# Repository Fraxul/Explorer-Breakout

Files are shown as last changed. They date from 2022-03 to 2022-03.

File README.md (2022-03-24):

# Lenovo Explorer cable breakout

This board is designed to replace the captive cable on a Lenovo Explorer Windows Mixed Reality HMD.
It was designed for use in an embedded system where the standard 3m cable is too long, but might be useful for other applications. It should also serve as a reference for the pinout of the explorer's data connector (or at least enough of it to get USB3 and HDMI working).

The project has been successfully tested with boards manufactured by Oshpark.

Note: If you have a 3d printer, print the included spacer and install it between the interface board and the motherboard so you don't put strain on the board-to-board connector. 0.2mm layers, 100% infill, no supports. Lay it flat with the pocket facing up.

### Known Issues

- The USB3 Type-A connector really should be a Type-C connector (or at least not an upstream-facing A connector!)
- The HDMI connector is too close to the USB3 connector: HDMI cables with large strain relief overmolds will not fit side-by-side with a USB3 plug. I use a slimline HDMI cable for this applcation -- MMonoprice 113578 is known to work.

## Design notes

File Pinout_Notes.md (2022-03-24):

Lenovo Explorer connector pinout (viewed from motherboard side)

|  | | |  |
|--|---|---|--|
|15|GND |GND |30|
|14|USB3 US\_TXM (w/ inline DC blocking cap on MB) |USB2 D- |29|
|13|USB3 US\_TXP (w/ inline DC blocking cap on MB) |USB2 D+ |28|
|12|GND |XXX to HT8181 2B? and unknown edge trace |27|
|11|USB3 US\_RXM (direct) |HDMI TMDS CLK+ |26|
|10|USB3 US\_RXP (direct) |HDMI TMDS CLK- |25|
|9  |GND |GND |24|
|8  |HDMI TMDS D0- |HDMI SCL (15) |23|
|7  |HDMI TMDS D0+ |HDMI SDA (16) |22|
|6  |GND |HDMI HPD (19) |21|
|5  |HDMI TMDS D1- |HDMI +5V (18) |20|
|4  |HDMI TMDS D1+ |XXX to USB3 retimer? and unknown edge trace |19|
|3  |XXX to HT8181 2C? |HDMI CEC (13) |18|
|2  |HDMI TMDS D2- |USB VBus |17|
|1  |HDMI TMDS D2+ |USB VBus |16|

Motherboard connector is [Molex 547220304](https://www.molex.com/molex/products/part-detail/pcb_receptacles/0547220304)
Mating connector (on cable PCB) is [Molex 555600307](https://www.molex.com/molex/products/part-detail/pcb_headers/0555600307)

HT8181 ball grid (top view)

|4 |3 |2 |1 | |
|---|---|---|---|-|
| |Out TMDS CLK-  |Out TMDS CLK+ | |H|
|In TMDS D0- | | |Out TMDS D0- |G|
|In TMDS D0+ | |In/Out HDMI HPD? |Out TMDS D0+ |F|
|In TMDS D1- | | |Out TMDS D1- |E|
|In TMDS D1+ | | |Out TMDS D1+ |D|
|In TMDS D2- | | |Out TMDS D2- |C|
|In TMDS D2+ | | |Out TMDS D2+ |B|
|In TMDS CLK- | |In TMDS CLK+ | |A|

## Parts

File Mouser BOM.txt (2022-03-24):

Board-to-Board Connector: 538-55560-0307
USB3 Connector: 538-48393-0003
HDMI Connector: 649-10029449-111RLF

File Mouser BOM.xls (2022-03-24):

EXPLORER BREAKOUT
Mouser # | Mfr. # | Manufacturer | Customer # | Description | RoHS | Lifecycle | Order Qty. | Price (USD) | Ext.: (USD)
538-55560-0307 | 55560-0307 | Molex |  | Board to Board & Mezzanine Connectors 30 Ckt Vert. Plug 0.5 mm SMT Dual-Row | RoHS Compliant |  | 1 | $2.85 | $2.85
538-48393-0003 | 48393-0003 | Molex |  | USB Connectors USB 3.0 F/A STD RA REC CH=4.0 15u' | RoHS Compliant |  | 1 | $2.91 | $2.91
649-10029449-111RLF | 10029449-111RLF | FCI / Amphenol |  | HDMI, Displayport & DVI Connectors HDMI REC TYPE A RA SMT | RoHS Compliant |  | 1 | $1.14 | $1.14

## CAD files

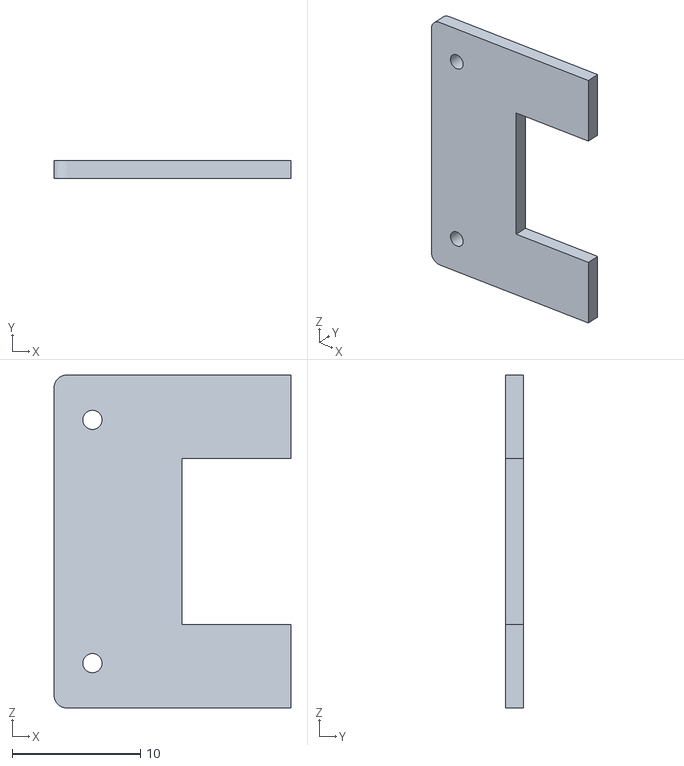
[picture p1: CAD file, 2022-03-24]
Explorer interface board spacer.STL
18.5 x 1.40 x 26.0

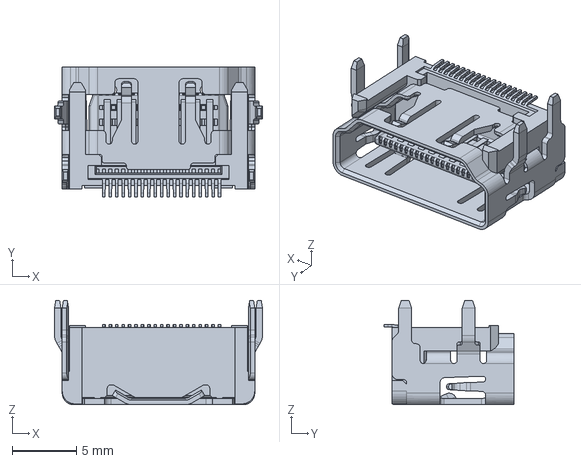
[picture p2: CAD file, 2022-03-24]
Footprints/10029449-111RLF.stp
16.2 x 10.1 x 8.13 mm

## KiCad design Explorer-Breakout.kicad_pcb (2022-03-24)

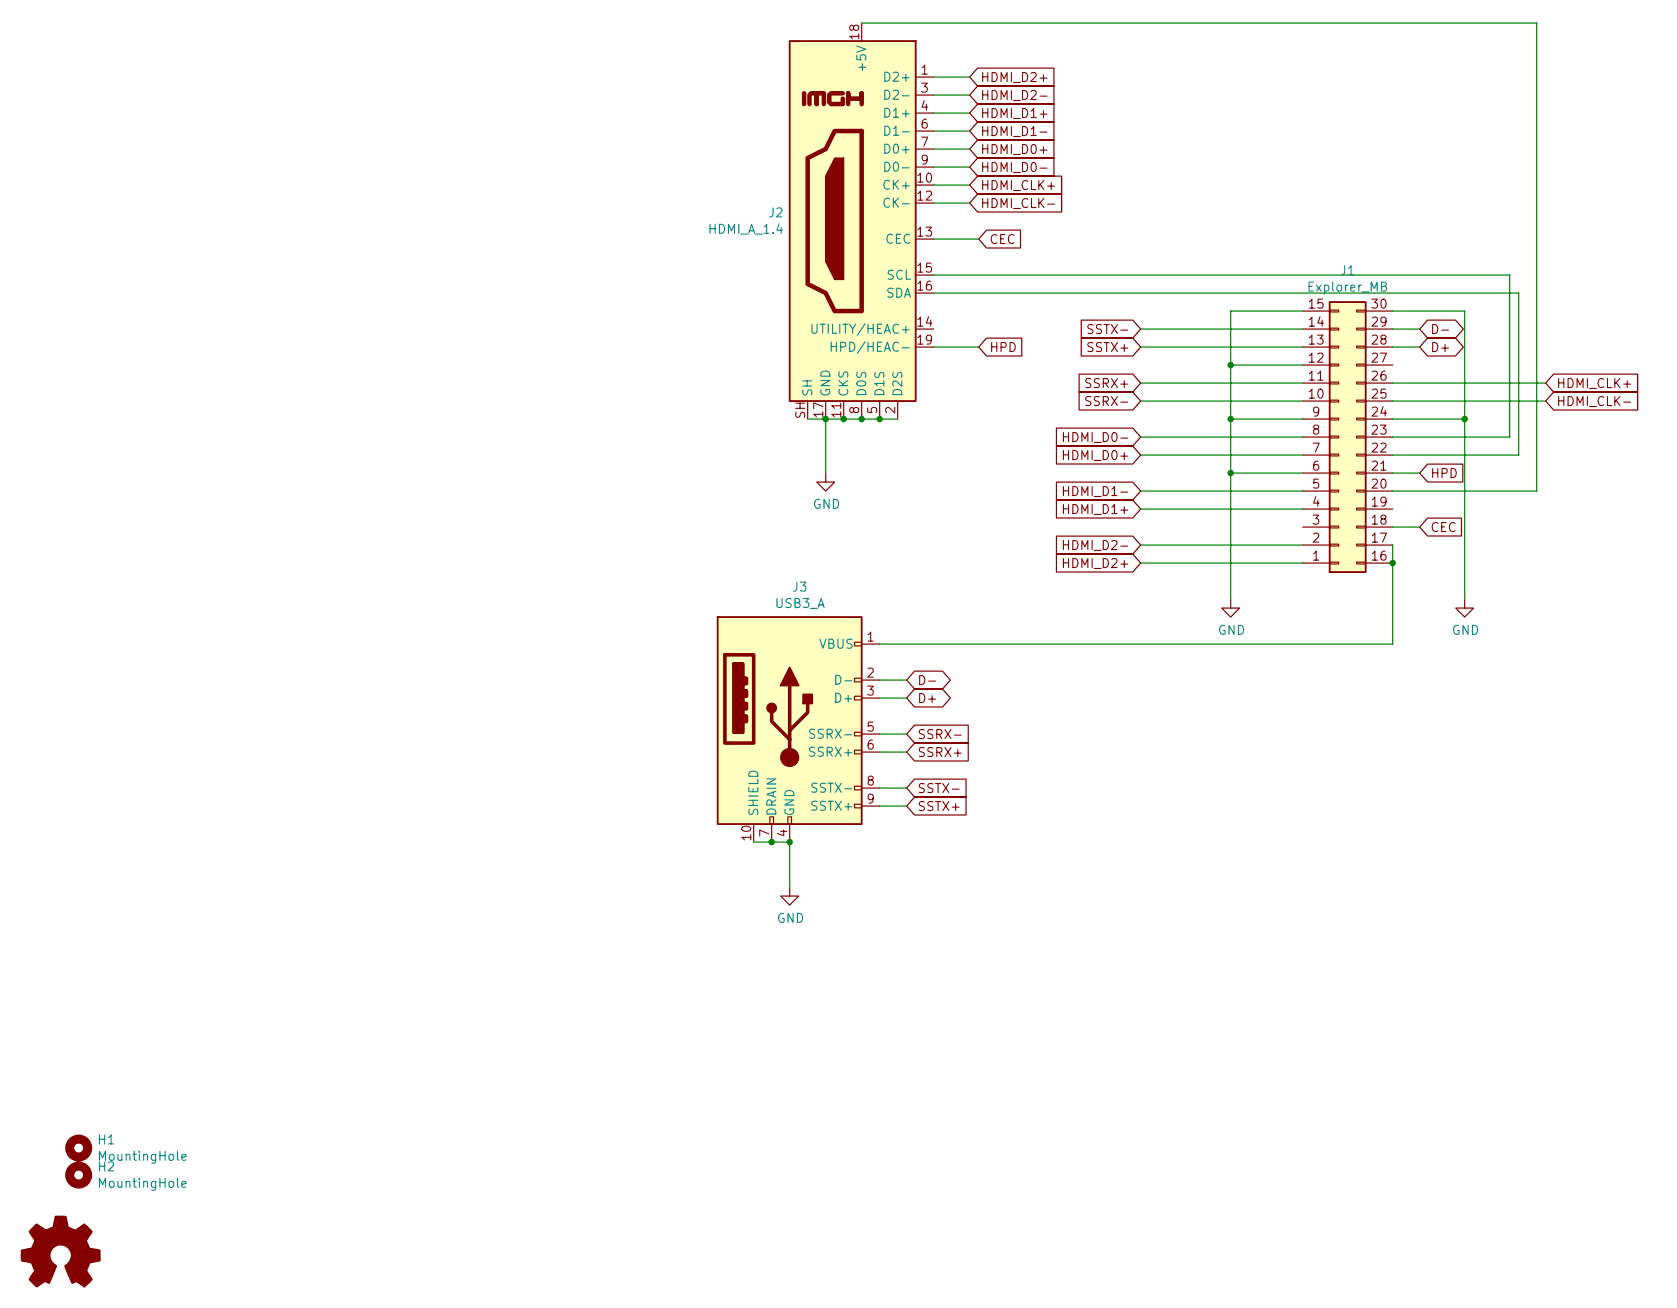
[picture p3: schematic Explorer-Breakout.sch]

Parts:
G1: Logo_Open_Hardware_Small; ZoidFace
H1, H2: MountingHole; MountingHole_1.5mm
J1: Explorer_MB; Molex_SlimStack_55560-0307_2x15_P0.50mm_Vertical_ColumnNumb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
J2: HDMI_A_1.4; HDMI_A_Amphenol_10029449-111
J3: USB3_A; USB3_A_Molex_48393-001

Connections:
CEC: J1.18, J2.13 (CEC)
D+: J1.28, J3.3 (D+)
D-: J1.29, J3.2 (D-)
GND: J1.6, J1.9, J1.12, J1.15, J1.24, J1.30, J2.2 (D2S), J2.5 (D1S), J2.8 (D0S), J2.11 (CKS), J2.17 (GND), J2.SH, J3.4 (GND), J3.7 (DRAIN), J3.10 (SHIELD)
HDMI_CLK+: J1.26, J2.10 (CK+)
HDMI_CLK-: J1.25, J2.12 (CK-)
HDMI_D0+: J1.7, J2.7 (D0+)
HDMI_D0-: J1.8, J2.9 (D0-)
HDMI_D1+: J1.4, J2.4 (D1+)
HDMI_D1-: J1.5, J2.6 (D1-)
HDMI_D2+: J1.1, J2.1 (D2+)
HDMI_D2-: J1.2, J2.3 (D2-)
HPD: J1.21, J2.19 (HPD/HEAC-)
unnamed: J1.16, J1.17, J3.1 (VBUS)
unnamed: J1.20, J2.18 (+5V)
unnamed: J1.22, J2.16 (SDA)
unnamed: J1.23, J2.15 (SCL)
SSRX+: J1.11, J3.6 (SSRX+)
SSRX-: J1.10, J3.5 (SSRX-)
SSTX+: J1.13, J3.9 (SSTX+)
SSTX-: J1.14, J3.8 (SSTX-)

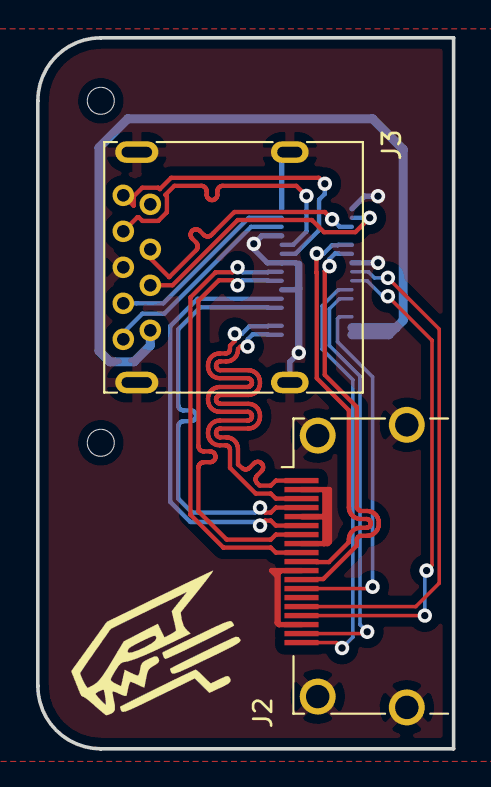
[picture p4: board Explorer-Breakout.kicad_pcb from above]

Board: 4 copper layers, 23.1 x 39.5 mm, 6 parts (1 on the bottom side), 21 nets.
